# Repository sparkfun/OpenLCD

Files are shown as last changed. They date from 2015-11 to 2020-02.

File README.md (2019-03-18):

OpenLCD 
=========

<table class="table table-hover table-striped table-bordered">
  <tr align="center">
   <td></td>
   <td></td>
   <td></td>
  </tr>
  <tr align="center">
    <td><a href="https://www.sparkfun.com/products/14072">SparkFun 16x2 SerLCD - Black on RGB 3.3V (LCD-14072)</a></td>
    <td><a href="https://www.sparkfun.com/products/14073">SparkFun 16x2 SerLCD - RGB on Black 3.3V (LCD-14073)</a></td>
    <td><a href="https://www.sparkfun.com/products/14074">SparkFun 20x4 SerLCD - Black on RGB 3.3V (LCD-14074)</a></td>
  </tr>
</table>

These AVR-based Serial Enabled LCDs are based on the HD44780 controller, and include an AVR ATmega328P with an Arduino compatible bootloader. They accept control commands via Serial, I2C and SPI. 

This repo contains the firmware that runs on the SerLCD hardware. If you are looking for the Arduino Library to talk to these devices please go [here](https://github.com/sparkfun/SparkFun_SerLCD_Arduino_Library).

And thank you to all those that helped make OpenLCD better:

* **fourstix** - [Creating](https://github.com/sparkfun/OpenLCD/pull/13) an Arduino library to drive OpenLCD directly, added pipe character escaping
* **makinako** - [Changing](https://github.com/sparkfun/OpenLCD/pull/18) EEPROM writes to updates to reduce NVM wear and tear
* **ALittleSlow** - [Fixed](https://github.com/sparkfun/OpenLCD/pull/21) logic bug on ignoreRX

Repository Contents
-------------------
* **/Firmware**
  * **/Examples**
  * **/OpenLCD**

Documentation
--------------
* **[SparkFun SerLCD Arduino Library](https://github.com/sparkfun/SparkFun_SerLCD_Arduino_Library)** - Makes printing to and controlling the SerLCD a snap!
* **[Hookup Guide](https://learn.sparkfun.com/tutorials/avr-based-serial-enabled-lcds-hookup-guide)** - Basic hookup guide for the SparkFun Open LCD Products.
* **[SparkFun Fritzing repo](https://github.com/sparkfun/Fritzing_Parts)** - Fritzing diagrams for SparkFun products.
* **[SparkFun 3D Model repo](https://github.com/sparkfun/3D_Models)** - 3D models of SparkFun products. 
* **[SparkFun Graphical Datasheets](https://github.com/sparkfun/Graphical_Datasheets)** -Graphical Datasheets for various SparkFun products.

Product Versions
----------------
* OpenLCD
  * [LCD-14072](https://www.sparkfun.com/products/14072) - SparkFun 16x2 SerLCD - Black on RGB 3.3V
  * [LCD-14073](https://www.sparkfun.com/products/14073) - SparkFun 16x2 SerLCD - RGB on Black 3.3V
  * [LCD-14074](https://www.sparkfun.com/products/14074) - SparkFun 20x4 SerLCD - Black on RGB 3.3V

License Information
-------------------
The code is beerware; if you see me (or any other SparkFun employee) at the local, and you've found our code helpful, please buy us a round!

Distributed as-is; no warranty is given.

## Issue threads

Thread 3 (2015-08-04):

Libraries for Reuploading the Default Firmware

bboyho, 2015-08-04:
It would be nice to include the additional libraries used for the default firmware in the repository. =) If not, it would be nice to include a link them somehow. I bricked the OpenLCD when trying to upload code to another Arduino. The pins were on the same hardware UART line. Doing a search online, I found the libraries:

SoftPWM library => https://code.google.com/p/rogue-code/wiki/SoftPWMLibraryDocumentation#Download

LiquidCrystalFast library from PJRC => https://www.pjrc.com/teensy/td_libs_LiquidCrystal.html

fourstix, 2018-08-24:
The link for the SoftPWM library in @bboyho 's comment now gives a 404 error.  It looks like the latest version of SoftPWM is now here on github https://github.com/bhagman/SoftPWM , also one can install SoftPWM through the
FWIW,  I second the suggestion to put links in the tutorial.  Also it may be possible to install these Libraries through the Arduino Library manager.  That might be the easiest thing to do.

fourstix, 2018-08-24:
(I don't know why github word-wrapped my comment like that. It should say:)
The link for the SoftPWM library in @bboyho 's comment now gives a 404 error.
It looks like the latest version of SoftPWM is now here on github https://github.com/bhagman/SoftPWM , also it may be possible to install these Libraries through the Arduino Library manager.
FWIW, I second the suggestion to put links in the tutorial.

bboyho, 2018-09-27:
If anyone needs to reupload OpenLCD's default firmware, the zipped libraries have been linked in the [Troubleshooting section](https://learn.sparkfun.com/tutorials/avr-based-serial-enabled-lcds-hookup-guide/troubleshooting) of the tutorial. I followed the "**Add .ZIP Library...**" route since the _Liquid Crystal Fast Library_ does not appear to be in GitHub or included in the Arduino IDE's Library Manager.

Closed 2018-09-27.

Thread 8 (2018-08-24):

Add function for printing the pipe character to the serLCD display

fourstix, 2018-08-24:
Currently pipe | is used as the command setting character, and printing a string with a pipe character may accidentally invoke a display function.  There currently is no way to print a string with a pipe character to the display.

Adding logic to allow pipe to be double escaped || would allow the user to print a pipe symbol as a character in a string without accidentally invoking a display command.

nseidle, 2018-08-25:
Yup! You fixed this in PR #7. Rock on and thanks for the help! Please let me know if you see anything else that needs fixing.

Closed 2018-08-25.

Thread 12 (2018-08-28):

Create library

nseidle, 2018-08-28:
We should really write a library for this device. It would be much easier if a .begin() function took a TwoWire, Serial, or SPI stream and then over-wrote the .print function. We did this on the Qwiic OpenLog product.

fourstix, 2018-08-28:
I already started down that path a bit.  I ported the LiquidCrystal library for Qwiic and the OpenLCD, which could be the I2C /TwoWire part.  It has Print class implemented and all the LiquidCrystal examples ported.  It's publicly available here on github: https://github.com/fourstix/QwiicSerLCD

I thought about expanding it to cover the other communication modes, but I was sure exactly how to best implement the selection of the communication interface type.  Is it best done in the begin() statement or in a constructor?    If there is a Sparkfun preferred way of doing it, I be glad to take a stab at it.  I just need some direction on how Sparkfun would prefer things to be done.

nseidle, 2018-08-28:
Nice!

[This is how](https://www.sparkfun.com/news/2194) we pass in Wire streams to libs so users can use Wire or WireX if they need it. You should be able to overload .being with functions that have TwoWire, SPIClass, and Stream depending on what the user passes in (Wire, SPI, Serial).

nseidle, 2018-08-28:
The [SCD30 library](https://github.com/sparkfun/SparkFun_SCD30_Arduino_Library/blob/master/src/SparkFun_SCD30_Arduino_Library.cpp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) is an ok example of TwoWire class passing.

fourstix, 2018-08-28:
That's Great!  I'll take a look at those examples and run with them.   It looks like I should factor out the initialization of Wire and make that external to the class.

What would like the library class to be called?  SerLiquidCrystal or something else?  Also, any particular example or conventions I should follow?  I can create a repository on Github, and then you could just fork it into Sparkfun once your happy with it.  (I'm a bit new to Git and Github, so please let me know the preferred way to do things.)

fourstix, 2018-08-28:
Hmmm.  LiquidCrystal has a begin function that takes two parameters, col and row, eg. begin(16, 2);  I'm wondering if it would be better to put the stream logic in the form of a constructor, maybe delegating to an init method if needed.  Something like SerLiquidCrystal(TwoWire& wireport).

 SerLiquidCrystal(Wire) lcd;
 lcd.begin(16, 2);

lcd.print("Hello, World!);

nseidle, 2018-08-29:
Library class: OpenLCD? I don't have anything better. Liquid Crystal is pretty well known and I don't want to confuse. Also, SerLCD reads as 'serial' LCD where it looks like you and I are both using Qwiic/I2C.

Sure, in the constructor works. I kind of prefer it in the .begin so that it's clear what options go with what stream. For example (and I haven't thought this through)

    .begin(Wire, 0x35) - where 0x35 is the I2C address of the display.
    .begin(SPI, 1000000) - where 1,000,000 is the SPI freq

.begin(16,2) is not needed as the SerLCD firmware auto-identifies the LCD size (via resistor).

Yep, eventual goal is lcd.print("Hello");

fourstix, 2018-08-29:
Constructor vs begin()
OK, that's a good point. Let's go with overloading begin() instead of overloading constructors.  My main objection was the number of arguments in begin() if one includes the row and column as well as the arguments for the communication type.  Since it's not necessary to specify row and column, it makes sense to put it there.  (If one has more than 5 arguments, other programmers will point and laugh at you.)

Class name
I'll start making the changes in the QwiicLiquidCrystal class, and we can change the name later.

Unfortunately the name OpenLCD is already used for the firmware class name.  It's generally a bad practice to name two classes the same thing, especially when they are somewhat related, but have different functions.

Personally, I like having "LiquidCrystal" in the class name, as this would be an implementation of that class.  I'm leaning toward something like LiquidCrystal_OpenLCD .  As a newbie, that would tell me this is the class to use my OpenLCD display with the LiquidCrystal functions.

fourstix, 2018-08-29:
I should have said I'll make the changes in the QwiicSerLCD repository for now.  We can move them to a new repository with the right class name, later.

fourstix, 2018-08-29:
Come to think of it.  Sparkfun_OpenLCD has a nice ring to it.  That might make a good class name for the Library.

fourstix, 2018-08-29:
I've got the TwoWire and Serial passing done.  Tested I2c via Qwiic and currently testing Serial using Software Serial on an Arduino Pro-Mini 3.3v / 8 MHz.  Working to implement SPI next.

fourstix, 2018-08-30:
@nseidle  I have SPI implemented and have tested Serial and SPI.  It seems to be working.  I2C still works fine as well.  It's available for review at https://github.com/fourstix/QwiicSerLCD

I can re-name it Sparkfun_OpenLCD and create a library directory in OpenLCD and submit a pull request, if you think it's ready.

fourstix, 2018-09-02:
The complete first implementation of the library is ready.  I'll create a pull request.

fourstix, 2018-09-02:
Pull request done.  @nseidle Please let me know what you think.  You're welcome to have @bboyho  or someone from QA review it and (in the words of the Blondie song) Rip 'er to shreds.   I'm always learning and welcome constructive criticism.  Have a great Labor Day!

nseidle, 2018-09-14:
This is really good. I'm going through converting it to fit our lib format. Couple things:

* You shouldn't do a Wire.setClock() before lcd.begin because the .begin() does a Wire.begin which reset the clock back to 100kHz. The fix is to move Wire.setClock after lcd.begin.
* Lots of examples is *really* good. But it's hard to tell where to begin. We put 'ExampleX-' before each example name so it's clear how the examples escalate.
* I changed name to "SerLCD" (dropped Qwiic) since your lib looks to work (nice job!) with SPI. We'll make it work with serial as well. We'll have to tailor a few examples (sub directories) so user knows which examples go with which communication protocol.

nseidle, 2018-09-14:
Another trick:

    #include <SerLCD.h> //Click here to get the library: http://librarymanager/All#SparkFun_SerLCD

fourstix, 2018-09-14:
Great points.  I didn't realize Wire.begin() reset the clock.   There probably are too many examples, since I ported every example from the LiquidCrystal library.  Feel free to omit or add anything you want.

FWIW, I tested the library using SoftwareSerial and it seemed to work, so hopefully I implemented the Serial part correctly.

nseidle, 2018-09-14:
Why is there a delay inside the clear function? This causes your backlight example to run slowly/oddly.

https://github.com/sparkfun/OpenLCD/pull/13/files#diff-7c78931ad272942267b7f87c7b351b24R261

nseidle, 2018-09-14:
Sorry for all the discussion, I'm understanding more of your lib. There is another 50ms delay in the setBacklight function. This is ok, but not ideal. I'm starting to see that the SerLCD firmware (not your lib) is somewhat slow. I think it's related to the amount of time it takes to write to EEPROM the backlight values...but it shouldn't be this slow. I'm still digging. But can you explain why you've got delays in clear() and setBacklight()? My code doesn't work when they're removed... so again I think it's LCD firmware related.

fourstix, 2018-09-14:
Yes, I just added delays empirically to try and reduce flicker or to avoid over-running data sent to the display.  For the backlight changes, it was done to avoid seeing the display messages.  I believe the new set RGB backlight function would avoid them and the delay would probably be unnecessary.  I ran a bunch of tests in a loop, and I think I had the display commands getting missed a few times.  Sometimes the data bytes would appear as a Japanese character rather than be interpreted as a command escape sequence to set the cursor position.  My guess was that I was just sending data too fast, and so I introduced a delay into the code.

fourstix, 2018-09-14:
I should have mentioned I was using the LiquidCrystal HelloWorld sketch to send commands over and over as a test.  It doesn't clear the display, but moves the cursor back to the second line, first column and prints over the previous value.  It prints the same number repeatedly until a second goes by.

 Occasionally, say once every 20 minutes or so, I'd see a glitch, A Japanese character followed by the seconds value sticking out past the normal seconds count.  It seemed to be the worst with SPI, better with SoftwareSerial and best with I2C.  I thought it was random noise from my jumper wires.

nseidle, 2018-09-14:
Excellent. Yep, I agree. There's a

    petSafeDelay(SYSTEM_MESSAGE_DELAY);

inside the changeBLBrightness() function in the OpenLCD firmware that's taking 500ms. That's the delay given me the headache.

There should be a faster way to change the backlight and your changeBacklightRGB() function is perfect. Do you foresee any issues [removing this delay](https://github.com/sparkfun/OpenLCD/blob/master/firmware/OpenLCD/Setting_Control.ino#L160) (and displayFrameBuffer()) from changeBackLightRGB()?

fourstix, 2018-09-14:
No, not at all.  I literally copied them from the previous function (cargo cult programming) thinking that they had to be there for a reason.

nseidle, 2018-09-16:
That is the best use of cargo cult I think I've heard.

Ok, I think I finished re-arranging your library. It's over on [this repo](https://github.com/sparkfun/SparkFun_SerLCD_Arduino_Library). [Request into Arduino](https://github.com/arduino/Arduino/issues/8003) for lib manager inclusion is in the works.

nseidle, 2018-09-16:
I'm going to close these issues out. Let's open new ones on the library repo as necessary.

Closed 2018-09-16.

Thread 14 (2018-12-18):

No Complete command list

justarandomgeek, 2018-12-18:
I can't seem to find a complete command list anywhere - the readme says nothing about commands, and the examples only include the "cheat sheet" list, even the ones that use commands that aren't on it (like custom characters).

lewispg228, 2018-12-18:
Hey @justarandomgeek ,
Sorry we don't currently have a 100% complete command set. Hopefully this [firmware overview](https://learn.sparkfun.com/tutorials/avr-based-serial-enabled-lcds-hookup-guide/firmware-overview) will be useful to you. The table at the top of this hookup guide section contains all of the most useful commands (and includes a few more than the cheat-sheets in the example code).

However, I just noticed that it omits some of the lower decimal values for setting width and line values. These early commands are actually not as useful anymore, because the new LCD screens check a hardware IO pin (pulled HIGH/LOW with hardware) to see what screen it is and sets the width and line values automatically. This is how we maintain the same firmware across all hardware.

Hope this helps!
-Pete

justarandomgeek, 2018-12-18:
It's also still missing all the custom-character commands (the example seems to suggest they ought to start at 0x1B? surely the docs should talk about that...), which indicates to me that it's still incomplete - and really, those are far more interesting than the screen-size ones!

To be clear: I'm wanting to use these screens with my own non-arduino boards, and to do that, I'm gonna have to write my own drivers. To do *that*, I need a complete command list, which I can't seem to find *anywhere*.

lewispg228, 2018-12-18:
Sorry about this. I haven't played around with the [custom char example yet](https://github.com/sparkfun/OpenLCD/blob/master/firmware/Examples/Serial/Example9_Serial_CustomChar/Example9_Serial_CustomChar.ino).  It is one of the more advanced features of these screens, and so we haven't provided as robust documentation for that yet. You are right, it would definitely be nice to get more info about custom char (possibly write up a few more examples) and provide a complete command list.

I will reach out to Nate (who wrote most of this new code for the LCDs). We should be able to pull together a complete command list and have that posted soon.

justarandomgeek, 2018-12-18:
Looking forward to that! Frankly, this is the first time (in 10+ years) that I've bought a SparkFun product and not loved it - and so far I'm *really* disappointed, you guys are slipping. You used to have perfect docs on every product!

nseidle, 2018-12-18:
I've added to the [command table](https://learn.sparkfun.com/tutorials/avr-based-serial-enabled-lcds-hookup-guide/firmware-overview). Should be complete now.

For the pertinent code (and my own notes):

* [Record custom char](https://github.com/sparkfun/OpenLCD/blob/master/firmware/OpenLCD/OpenLCD.ino#L379)
* [Display custom char](https://github.com/sparkfun/OpenLCD/blob/master/firmware/OpenLCD/OpenLCD.ino#L215)
* [Write RGB](https://github.com/sparkfun/OpenLCD/blob/master/firmware/OpenLCD/OpenLCD.ino#L220)
* [Display firmware version](https://github.com/sparkfun/OpenLCD/blob/master/firmware/OpenLCD/OpenLCD.ino#L225)

@justarandomgeek - Have a look and let me know if anything doesn't make sense and I'll add to it.

Closed 2018-12-18.

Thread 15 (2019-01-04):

Three Files with the Extension .ino prevent compile in Windows.

mitag, 2019-01-04:
The firmware consists of several files, three of which have the extension .ino. Yesterday I bought a 20x4 SerLCD and this has the known backlight bug in the firmware. On your side the procedure is described very well, but I could not compile the firmware under Windows 10, because only one file may have the extension .ino. Trying to rename the files to header files caused several problems. So I installed everything under Debian Linux and the three files with the extension .ino don't interfere! I forked the firmware and uploaded the binary file in the fork, because you fixed the bug but didn't upload a binary file. It's not that bad, but just to fix the bug, the steps are too extensive for most users.

[https://www.youtube.com/watch?v=OjE9r5SRFKM](url)

mitag, 2019-01-04:
For now, I've written a small [workeround](https://github.com/mitag/OpenLCD/blob/master/firmware/OpenLCD/README.md) in my fork.

nseidle, 2019-01-04:
Hmm. Weird. It is correct to have multiple INO files in a given directory. It's called tabs; we do it a lot to segment large sketches into various relevant buckets. Arduino opens multiple INOs correctly as shown

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

Sorry for not pushing a hex file. I can get that into the next release.

Thanks for trying to upgrade your 20x4! Let me know if you continue to have issues. I'm going to close this issue because I don't *think* it's an issue. Please correct me if you still have problems.

per1234, 2019-01-06:
The issue turned out to be caused by a bug in arduino-builder, which has already been fixed.

Details: https://github.com/arduino/Arduino/issues/8360#issuecomment-451708341

Closed 2019-01-04.

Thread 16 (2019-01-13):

Reduce the number of EEPROM writes with a 'Save Settings' command or EEPROM.update

makinako, 2019-01-13:
EEPROM.write is used all over the place to save settings on-the-fly (without an explicit 'save settings' command). Since sketches will mostly configure the SerLCD in setup(), this means that every time the sketch starts (at least) it is writing to the EEPROM a number of times for Backlight, Contrast, etc. It also dramatically slows the operation down.

Two solutions:
1. Simply change all calls for EEPROM.write to EEPROM.update, which will check if the value has changed first
2. Remove all the calls to EEPROM.write and have a specific 'Save Settings' command, so that all changes occur only in RAM unless persisted.

Option 2 is the more performant one, but Option 1 is probably preferred because of compatibility.

makinako, 2019-01-25:
Just to put it in context for how I use it, I am connecting to a SerLCD module via UART. At reset, because I can't read what the current settings are I configure the SerLCD module as if it was the first time, which includes contrast, backlight, etc.
On top of this, our device has a sleep mode which turns off the LCD and backlight after a minute of inactivity. The backlight needs to be turned off separately here because the display on/off command doesn't affect it.
Extending this beyond my own application, if someone else allowed these parameters to be adjusted via trimpots or similar, this could result on a rapid succession of EEPROM writes.

The EEPROM.update change would largely get rid of this problem, but another firmware solution at least in my use case would be to read the current settings. I had considered just recording the last settings in my own EEPROM, but we have built 20 of these devices (8-channel audio recorders with LCD UI) and some of them have already had their LCD modules swapped out, which my firmware wouldn't have been aware of.

Hope this clears up the intent at least. There may be a better way to do what I'm doing that I haven't come up with. It's certainly not a high-priority issue but considering it's most likely just a search/replace of EEPROM.write to EEPROM.update it is a fairly easy fix with hopefully some performance implications as well (when updating rapidly). I'd be more than happy to fork/change/test it and submit as a pull request if you were inclined to go down this path!

nseidle, 2019-01-25:
Ah, yes that makes more sense to me now, thanks. Indeed, your update() recommendation is a much better way to go.

I would be thrilled with a PR if you get that far. I plan to spend some time on the firmware early next week so please PR as far as you get and I can pickup where you leave off.

makinako, 2019-01-30:
Changes merged and tested by @nseidle! Closing this baby down.

Closed 2019-01-30.

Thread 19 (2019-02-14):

Turning off system messages

jamesraylittle, 2019-02-14:
I cannot find anywhere in the documentation on how to turn off system messages.
I have also dig through the code a bit and at a glance it does not look like a command of that nature exists.

When using the example code below:

```
  Wire.beginTransmission(LCD_1_ADDR); // transmit to device
  Wire.write('|');
  Wire.write(128);
  Wire.write('|');
  Wire.write(187);
  Wire.write('|');
  Wire.write(188);
  Wire.endTransmission(); //Stop I2C transmission
```

This will then display three separate messages on the LCD.

nseidle, 2019-02-14:
You can turn on/off the splash screen. Are you're asking how to turn off messages like the "Contrast Set" and "New TWI: 0x52" and what not?

jamesraylittle, 2019-02-14:
Correct,

The system messages that happen after updating a value for a setting, such as `Contrast Set...`

nseidle, 2019-02-15:
Should be easy enough to implement. Have you been able to update the firmware on your SerLCD? It will be a while before we get this feature rolled out onto stock units.

nseidle, 2019-02-15:
Lots of changes but [this commit](https://github.com/sparkfun/OpenLCD/commit/2a9d4e230b6623294a690a88542e33e8e07938de) should allow for disable/enable of system messages. If you have the chance, please try it on your hardware.

Attached is HEX file that should be loadable on your display.

[OpenLCD.ino.arduino_standard.zip](https://github.com/sparkfun/OpenLCD/files/2870768/OpenLCD.ino.arduino_standard.zip)

jamesraylittle, 2019-02-15:
I have no tried updating the LCD firmware, but after reading the instructions, it seems easy enough.

I will report back.

jamesraylittle, 2019-02-16:
Are these parameters correct for avrdude?

`avrdude -c avrispmkII -p m328p -P /dev/cu.usbserial-DN02SHFI OpenLCD.ino.arduino_standard.hex`

jamesraylittle, 2019-02-16:
I had a bit of trouble updating the firmware, I had to move over to a windows machine to get the `Fast LCD` library to compile. I wasn't 100% sure on just uploading a the hex file using avrdude, I was getting a lot of timeouts and documentation is lacking in that area.

I looked at the last commit and I noticed this in the file `OpenLCD.ino` starting at line `242`
```
//Enable or disable the displaying of system messages
    else if (incoming == 46) //. character
```

I made the assumption that system messages are left on by default.

Here is my test program:

```

#include <Wire.h>

#define DISPLAY_ADDRESS1 0x72 //This is the default address of the OpenLCD

int _calculateValue(int value, int minValue, int maxValue) {
  return minValue + round( (value / 100.0) * (maxValue - minValue));
}

void setBackground(int red, int green, int blue) {
  /*
  / 128-157 / 0x80-0x9D - Set the primary backlight brightness. 128 = Off, 157 = 100%.
  / 158-187 / 0x9E-0xBB - Set the green backlight brightness. 158 = Off, 187 = 100%.
  / 188-217 / 0xBC-0xD9 - Set the blue backlight brightness. 188 = Off, 217 = 100%.
  */
  int redValue = _calculateValue(red, 128, 157);
  int greenValue = _calculateValue(green, 158, 187);
  int blueValue = _calculateValue(blue, 188, 217);

  Wire.beginTransmission(DISPLAY_ADDRESS1);
  Wire.write('|');
  Wire.write(redValue);
  Wire.write('|');
  Wire.write(greenValue);
  Wire.write('|');
  Wire.write(blueValue);
  Wire.endTransmission();
}

void setup() {
  Wire.begin(); //Join the bus as master

  //By default .begin() will set I2C SCL to Standard Speed mode of 100kHz
  Wire.setClock(400000); //Optional - set I2C SCL to High Speed Mode of 400kHz

  Serial.begin(9600); //Start serial communication at 9600 for debug statements

  //Send the reset command to the display - this forces the cursor to return to the beginning of the display
  Wire.beginTransmission(DISPLAY_ADDRESS1);
  Wire.write('|'); //Put LCD into setting mode
  Wire.write('-'); //Send clear display command
  Wire.write('|'); //setting mode
  Wire.write(46); // disable system messages
  Wire.endTransmission();

  setBackground(0, 0, 0);

  delay(2000);
}

void loop() {
  //red
  setBackground(100, 0, 0);
  delay(10000);

  //green
  setBackground(0, 100, 0);
  delay(10000);

  //blue
  setBackground(100, 0, 0);
  delay(10000);
}
```

I do see a system message that does say `System Messages ON`

Removing the two lines from setup
```
  //Wire.write('|'); //setting mode
  //Wire.write(46); // disable system messages
```

I no longer see the message `System Settings: ON`, but I still see system messages.

nseidle, 2019-02-16:
My bad. I thought the compiler would toggle the bool correctly. It doesn't.

New code pushed. All tested and shiny. Hex is attached (for your convenience). I've also updated the SerLCD library to support the enable/disable commands, added examples as well.

I also added discrete enableSplash() / disableSplash() commands while I was in there.

[OpenLCD.ino.arduino_standard.zip](https://github.com/sparkfun/OpenLCD/files/2872392/OpenLCD.ino.arduino_standard.zip)

Please reopen if you have any other issues.

Closed 2019-02-16.

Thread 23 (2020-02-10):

Persistent faint blue backlight when backlight is set to off (0,0,0) and on initial power on.

rustycoat, 2020-02-10:
Although it is not noticeable in the daytime, there is a constant very faint blue backlight on my unit. This occurs on startup, and also persists even after setting the backlight to 0x00, 0x00, 0x00 with the provided sample code (write: |, -, |, +, 0x00, 0x00, 0x00).

This is over i2c. All other functions seem to perform fine. This has been tested both with direct I2C commands and with the SerLCD library.

fourstix, 2020-02-10:
Hi, I think that's an design artifact from using PWM to control the Blue backlight.  From looking at the source code the blue backlight is controlled by using PWM to dim the output.

If I remember right, PWM is not necessarily an absolutely rock solid line at 100% duty cycle, so I think you are seeing the blue value dimmed to a very small value that is considered zero.

But not actually a perfectly flat zero line, as there are tiny little intervals where the blue light pulses on then off, very briefly, very faintly, that most people wouldn't notice.   But your eyes are sensitive enough to see it to see it as a faint blue glow.  My guess is mine glows just the same as yours, I just don't see it.

I'm not expert and I don't work for Sparkfun. This is just my theory from looking at the code.

Good luck to you.

hbirch, 2020-02-11:
Thanks for the tip -- although I tend to be on the sensitive side when it comes to senses, I do believe it's very easily seen at night. In daytime you can only see it from the side of the LCD. It's about as bright as a dim nightlight or a fading indiglo watch from the 80s.

I would think if they use PWM they would have a conditional for 100% and 0% for true on and off to bypass that needless logic/circuitry in that case. Seems easy enough, though the phrase "the SerLCD v2.5 pulse width modulates the backlight via a 1A BJT transistor" makes me wonder if that transistor is not bypassable. I'm from a software not a hardware background so I am likely misguided on my expectations here as I know what's trivial programmatically may not translate easily onto the circuit board.

That said: a consumer device with the backlight set to "off" should definitely not be illuminating one's bedroom at night. I think the expectation that off is off is fairly reasonable.

If yours can't be seen at night with all the lights off then I'm guessing I may just have a hardware problem where the PWM transistor mentioned above is not manufactured to spec in my individual unit?

nseidle, 2020-02-11:
@hbirch - Thanks for reporting! I agree with fourstix. It's probably a software issue, not hardware. We're looking into it this week.

hbirch, 2020-02-12:
Thanks. Am I right that PR#22 from March 2019 fixes this? It appears to be addressing the same issue.

Unfortunately, this probably means I will need to purchase the FTDI adapter to update firmware...

lewispg228, 2020-02-18:
Hey All,
Thanks for submitting this issue, and thanks to everyone chiming in.

I just verified that pull request #22 does fix this issue. We are currently working on getting this new fimrware (v14) into production. But if you'd like to update your current unit, @rustycoat , then yes, you'll need an FTDI adapter (make sure you use a 3.3V logic level).

We have these in both USB-C connectors:

https://www.sparkfun.com/products/15096

And microB:

https://www.sparkfun.com/products/14050

Thanks again everyone!

Closed 2020-02-18.

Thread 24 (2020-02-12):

Internal i2c pull up on LCD-14074

hbirch, 2020-02-12:
I've run across a reference somewhere that OpenLCD uses a 4.7k internal pull up resistor on SDA/SCL, but that reference was for non-RGB older versions. The hookup diagram on sparkfun makes no mention of any internal pull-up (OR how to disable it).

Does this pull up exist and if so how can it be disabled?

hbirch, 2020-02-12:
Looks like it is labelled on the board. I will note that there is NO documentation whatsoever of this in the hookup guide.

Closed 2020-02-12.

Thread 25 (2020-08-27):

(More a question than bug report)

Just-another-pleb, 2020-08-27:
I don't know an easier way to get in touch with you about this display.
I use Node-Red on a RasPi.

I have a display which I have been told is covered by this bit of software.

Alas I think what you have is for Arduinos / etc, and not for Node-Red.

No problem.

The RasPi and the display are 3.3v, so that is good.
I got it, hooked it up and used someone else's *node* but it would seem I have opened a can of hurt.

I am wanting a node to talk to this display and send it commands like:
backlight (on/off)
cursor (on/off)
blink (on/off)
and x/y positioning for text.
Though if the x/y is missing, it just prints at the next position.

Could you help me?

fourstix, 2020-08-27:
Hi,
I have only played with Node-Red a little bit, but I think what you want to do is to create a custom node for the LCD.   Node-Red has a page how to create custom nodes for a component.  You could use the same commands as in the Arduino based code to control the OpenLCD in your custom node.

There's a guide on creating a new node available here:
https://nodered.org/docs/creating-nodes/

Once you've created the node and tested it.  I believe you can publish it so other Node-Red users can use it.

Good luck,
Gaston

Just-another-pleb, 2020-08-27:
I was kind of hoping that someone else had done that, but their I2C address is 27 but on the RasPi when I scan for it: it shows at address 72.

Thanks.

I think I can *back engineer* it if I look hard and long enough at the Arduino code and the code for the existing node - which has the wrong address.

Thanks though.

I may still need your help.   (If you don't mind)

Just-another-pleb, 2020-08-29:
I am still not really getting any useful/helpful replies from SparkFun on the specs of this.

However, reading what I can find, and what is in this .... system, it should work but isn't.

The display (and AVR) come with this .... _QWIIC_ already loaded.
Looking at that, QWIIC is something to do with the I2C bus.   Great!

We've been over that.   That is how I am connecting it to the RasPi.

But when I start going into that stuff, all the links loop back on themselves.  Which isn't helpful.

In this software I have seen python code to do things.   But is that code run on .....   Where?  On the AVR or the machine connected to the display?

It is confusing to me what is going on.

nseidle, 2020-08-31:
Sorry for the confusion. This repo is the firmware that is loaded onto our displays. It's written in C.

What you are asking for is assistance with the Python code that you will want to run on your RPi. Please see this [repo](https://github.com/sparkfun/Qwiic_SerLCD_Py) and consider posting an issue there.

Just-another-pleb, 2020-08-31:
My problem is that the firmware flashed into the firmware is buggy.

When I change the backlight value a message is printed on the screen informing me of this.

Ok, nice if that would be helpful to me, but it isn't and it causes confusion with the scripts running.

It would be nice if this _feature_ could be disabled.

So what I am (now) looking for is the firmware loaded into the display so I can modify it to not do what it is doing.

Oh, and running the demo scripts that come from Sparkfun on how to use it.
Horrible.

Example 2 and 13.

One of them waits 5 seconds between colour changes.  The other 2 seconds.

Weirdly the one which waits 2 seconds works.  The one which waits 5 seconds the colour names and the colours shown are very much out of sync.

Closed 2020-08-31.

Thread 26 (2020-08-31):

Erroneous messages on display when adjusting back light

Just-another-pleb, 2020-08-31:
After a lot of work, I got the display working.

Attached video explanation:

The display is showing me the time/date/day of week.
And there are a couple of problems visible that the messages are not quite working as they get their positions wrong now and then.
(That's probably an I2C noise issue.  But it is not this problem)

So the display has a _backlight_ of 255,255,255.  Though the colour is not exactly correct as you see it, I think that is more to do with the angle at which is it viewed.   However, the problem will become apparent when you continue watching the video.

I have opened a python (2.x) shell and typed in all but the last command shown here, now.
There is **no** implication that python3.x is supported or there is even a 3.x package available.

`
pi@alarmclock:~/.node-red$ python
Python 2.7.16 (default, Oct 10 2019, 22:02:15)
[GCC 8.3.0] on linux2
Type "help", "copyright", "credits" or "license" for more information.
>>> from __future__ import print_function
>>> import qwiic_serlcd
>>> import time
>>> import sys
>>> myLCD = qwiic_serlcd.QwiicSerlcd()
>>> myLCD.setBacklight(150,0,0)
`

You see the display happily showing the time.

I enter the last line:  `myLCD.setBacklight(150,0,0)` and watch what happens.

The display colour changes.  Not once, not twice but many times.
Simply from me entering the ONE command.

Also see ~~the~~ a colour name top left.
Nothing to do with the colour of the backlight.
Then towards the end you see the screen is covered with numbers.
My suspicion is that is the time being _forced_ all over the place.

So, problems - as I see them:
- There is a `backlight` command.  You enter it with a `r,g,b` parameter and it shows you a whole bunch of back ground colours.
- When the back ground colour is adjusted a random/nominal colour name is printed on the screen.  Top left.
- I have tried the `contrast` command and looking at the screen, I can't see any changes.
It isn't documented how to use other than something like:  _The lower the number, the higher the contrast._
Ok, so if you want a high contrast display, enter `0` - I guess.
It doesn't say if the LOWEST number is `0` or `1`.
And what is the highest number?
(Maybe this is a documentation problem and not for here, but I am quite happy to create a bug report there **IF** I can find the link.)

[LCD.zip](https://github.com/sparkfun/OpenLCD/files/5152699/LCD.zip)

fourstix, 2020-08-31:
>There is no implication that python3.x is supported or there is even a 3.x package available.

There's a Circuit Python library written in Python 3 available for this display. The Arduino examples are available as examples in the Circuit Python library.

 Information and install instructions are available here:  https://github.com/fourstix/Sparkfun_CircuitPython_SerLCD

Just-another-pleb, 2020-08-31:
I am connecting the display - out of the box - to a RasPi.

After messing around and many trips down wasteful links I discovered I had to install SparkFun's qwiic package.

The display then started to work as a display.

It came with a heap of example python files which were nice and did help me get things to where they are/were on the video clip.

But when it comes to adjusting the back light:  all bets are off.

I was _sent here_ because I was showing people how I was talking to the display using `python2.7`.

**you have to use `pythono3.x**

This entire scenario is not nice.
The display is great - in the concept of a display - but when it comes to the firmware showing messages on the screen when I send it a command to adjust the back light is just unbelievable.

And that the colour it says is not exactly related to the colour shown.   That's just not acceptable.

I shall try that new link and see what happens.

Thanks.

Just-another-pleb, 2020-08-31:
I have to say:  At least you **are** helping me.

Sparkfun are **NOT**.

The problem now is that the original lot of stuff I got - for 2.7 - had a lot of example scripts which I could then deconstruct and get the commands to do what I want.

Although there is a *demo script* it assumes all the other boards are there and needs a new kind of MQTT (from what I could read).

Where can I get a list of the commands I can use in Python3.x to talk to the display?

Thanks in advance.

fourstix, 2020-08-31:
I would suggest looking at the python libraries to see how they send commands to the display.

You can take a look inside  the file [sparkfun_serlcd.py](https://github.com/fourstix/Sparkfun_CircuitPython_SerLCD/blob/master/sparkfun_serlcd.py) to see how the CircuitPython library I wrote sends commands to the display.  If you want to see how to send the command's yourself, you will need to go digging.

But the easiest thing to do is to install a library either Sparkfun's Qwiic_Py library or Adafruit's CircuitPython library and then use the library class for the device to handle the commands.   I wrote the CircuitPython library because I wanted to mix and match Sparkfun and Adafruit components in CircuitPython.

Good luck to you!

Just-another-pleb, 2020-08-31:
I have installed the library - or I hope I have.

That is this one - yes?    [https://github.com/fourstix/Sparkfun_CircuitPython_SerLCD](url)

Done, but I am at a loss where the commands are _defined_

Though I am not really able to decode them.   I am able to see it _better_ when they are in code and I can see the structure that way.

What also derails any possibility of me understanding anything is that once I installed the library with the pip3 command, and I `cd` to it and then into the directory for the display - or the one I think is it - there are some files:
`INSTALLER` `LICENSE` `METADATA` `RECORD` and so on.

`INSTALLER` says `pip` and not `pip3`.

All my problems are because I used `pip` to install things and not `pip3`.
To install this I had to use `pip3`.

Why/how is it _LEGAL_ (you tell me a better word) for software which needs to be installed with `pip3` to then use `pip`?

fourstix, 2020-08-31:
Depends on how your Raspbian is set up.  Pip3 is always Python3 but the default Pip can point to either Python 2.7 or 3.

If you click on the link in the highlighted file name in my previous message that will take you directly to the source code file on GitHub and you  can see the actual code there.  Viewing the source file on GitHub is often easier to me, than digging in the directory structure :-)

Just-another-pleb, 2020-09-01:
Yes, I went there.  Thanks.

But I am not able to see the commands as I explained in the other post.

Example scripts are wonderful for me, as I again explained.   I know there is a base line of what the command is and expects.
But reading the source code and trying to extrapolate the command fails for me miserably.

You didn't explain the `INSTALLER` and why it says `pip` and not `pip3`.
I did see the "Depends on how the raspi is set up", but if I am told I need to install it with pip3 because pip installs the wrong version, then the version that is installed also needs to use pip3.

It can't use pip, otherwise when I did the `pip`, I would have installed/got this version, not the older one.

Just-another-pleb, 2020-09-01:
Good news.  Bad news.
Well, honestly that is what it is.

I don't know what/why or anything else.

I did the stuff again (there is a sever feeling of De Ja Vous) but for python3.

All the stuff.....

The node-red flow didn't show anything when run.

Honestly.  I don't know.

The flow is now working.

But the original problem persists:

When I change the background colour, the display shows/scrolls through several colours and there are messages printed on the screen which were not asked for by me.

I'll now go to the newer link and post there.

Just-another-pleb, 2020-09-01:
Oh sorry.   Closed now.

Closed 2020-09-01.

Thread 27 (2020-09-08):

Please add a command to disable serial input

ArizonaClark, 2020-09-08:
I would like to request a new command to ignore serial input (separate from the "ignore-RX on reset"), which would have the controller ignore anything happening on the serial RX line.  (It should be "volatile" in that it goes away whenever the display is reset or power cycled, IMHO.)  To maintain symmetry (always a good idea) there should also be disable commands for SPI and I2C.  (At the risk of pointing out the obvious, if these were "non-volatile" [as is the "ignore-RX on reset"], it would be too easy to "brick" the processor, thus best to make them "volatile".)

For "why", please see this Forum thread: https://forum.sparkfun.com/viewtopic.php?f=63&t=53788

alexandertmills, 2021-11-26:
Any update on this? Fix would be greatly appreciated.

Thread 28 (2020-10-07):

Characters being deleted when changing backlight?

mrmakeit, 2020-10-07:
Getting a weird bug whenever I try to change the backlight over I2C.  Any time I do so, the screen will delete a character, usually the last one from the current message, though repeating the change will delete more and more characters.   Any idea why this is happening?

nseidle, 2020-10-07:
Thanks for reporting. Do you have example code that demonstrates the issue so we can reproduce?

mrmakeit, 2020-10-07:
```
import qwiic_serlcd
lcd = qwiic_serlcd.QwiicSerlcd()
lcd.begin()
lcd.setContrast(5)
lcd.clearScreen()
lcd.print("Hello World")
lcd.setBacklight(0,0,0)
#'d' should now disappear from 'World'
lcd.setBacklight(100,100,255)
#'l' should now disappear from 'World'
```

nseidle, 2020-10-07:
Ah, this repo is the firmware that runs on the LCD. I suspect it's python library related. I've moved your issue to [that repo](https://github.com/sparkfun/Qwiic_SerLCD_Py/issues/4).

mrmakeit, 2020-10-07:
I've had the same issue with an arduino setup as well... Originally thought it was the arduino library, so I tested it with the above python.

nseidle, 2020-10-07:
Ok, feel free to post an example problem sketch on the [Arduino library](https://github.com/sparkfun/SparkFun_SerLCD_Arduino_Library/issues). If we pin it down to firmware on the LCD, then... well, I'll move some issues again :)

Closed 2020-10-07.

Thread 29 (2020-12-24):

Circular Buffer for 2004 not long enough

andrewcharnley, 2020-12-24:
More than 32 characters crashes the display. I've not had a chance to investigate further but it is consistent. This is a problem for those of us doing DMA writes of the entire screen.

nseidle, 2020-12-28:
Sorry, I need to get an issue template on this repo:

What micro or processor are you using to drive the display? What interface (I2C, serial, or SPI)? What driver (our Arduino library, probably your own)?

Code to replicate the issue would be immensely helpful.

Can you be more specific about the crash? Unit freezes until power cycle, unit displays garbage, etc.

I suspect you're hitting the 32 byte I2C buffer limit used in Arduino (the limit is in our peripheral. Not knowing your setup I can only guess that you might as well). Again, without knowing how you're interfacing to the display, I'm really just guessing.

andrewcharnley, 2020-12-28:
Sounds plausable. I2C using a NRF52.

I work around it by DMA'ing a row in 4 goes with a timer and counter. You should be able to easily replicate it, just write/print more than a line (line and a half will do it) and the display will lock up.

nseidle, 2020-12-28:
What is the size of the I2C buffer on nRF52?

I can replicate with an Artemis. Unit stops responding to I2C commands until power cycle.

     lcd.print("1234567890123456789012345678901"); //Good
  //lcd.print("12345678901234567890123456789012"); //Good
  //lcd.print("123456789012345678901234567890123"); //Good
  //lcd.print("1234567890123456789012345678901234"); //Fails

Curiously 33 bytes works. It's not immediately clear to me why the [I2C ISR](https://github.com/sparkfun/OpenLCD/blob/master/firmware/OpenLCD/System_Functions.ino#L49) is going off into never never land but I do believe it's Arduino core / I2C 32 byte buffer related.

Thanks for reporting. We won't be hacking the arduino core to support larger I2C buffers. For now your best solution is to limit your writes to 32 bytes. Let me know if you're using our [Arduino library](https://github.com/sparkfun/SparkFun_SerLCD_Arduino_Library). If you are, we can modify the [write function](https://github.com/sparkfun/SparkFun_SerLCD_Arduino_Library/blob/master/src/SerLCD.cpp#L403) to break large transfers into I2C buffer sized chunks.

andrewcharnley, 2020-12-28:
I generally use Arduino as a last resort, but since the firmware is embedded I don't see why you can't implement and include a patch file (in the rare case someone really wants to apply it manually). Personally I just want it working out the box, which I guess is the same for most people. Is the 32 byte referring to the circular buffer? I believe the Arduino is servicing the I2C buffer by interrupt but my experience with the HD controller used in the display is it uses a 50us delay between characters, so it's probably a race between completing those and the buffer filling up at 100kbs.

The I2C buffer on the NRF52 is limited only by RAM as it's DMA based. I wired up a timer to write chucks of 20 bytes one after the other with a little delay to allow the display/arduino code to recover. It works well enough.

fourstix, 2020-12-29:
I believe the 32 byte limitation is a limitation of the Wire library.

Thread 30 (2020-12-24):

Map special characters to unused ascii characters

andrewcharnley, 2020-12-24:
Please use the logic of the original HD chip! Those of us doing DMA writes of the whole screen can not use adhoc commands to change characters.

nseidle, 2020-12-28:
What micro or processor are you using to drive the display? What interface (I2C, serial, or SPI)? What driver (our Arduino library, probably your own)?

Your issue title is related to special characters but you're reporting issues with pass through low level HD44780 commands? Your issue is unfortunately too sparse for us to be of any help.

andrewcharnley, 2020-12-28:
I2C, NRF52.

I currently implement a screen buffer of 4x20 bytes which I write to and push out to the display. Apart from the other issue that I mentioned in the other thread, when special characters are used the command character must be used which prevents use of a screen buffer (because it's two bytes).

The simple solution is not to reinvent the wheel - use the non-print characters as spaceholders (0x0 to 0x20 or 0x7F) to a) invoke command options and b) to write special characters.

nseidle, 2020-12-28:
I welcome a PR. There's over 15 years of history to this product so you may be battling reverse compatibility of prior models.

andrewcharnley, 2020-12-28:
Time for a version 2.0 then. Solve all these problems and you have a one stop product for more professional use cases (DMA). ;)

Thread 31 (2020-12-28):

Use a separate command for writing flash

andrewcharnley, 2020-12-28:
Having a multi coloured display is a real bonus, I can use it to indicate errors and the like.

But if I flash/change colours a few times that's a couple writes to EPROM, and the 100,000 count will eventually be used up. It also slows the whole system down by locking the CPU while it writes.

Solution is to remove the auto-save and map it to a character in the 0x0 to 0x20 region.

nseidle, 2020-12-29:
I'm hesitant to implement mapping directly to the 0x0-0x19 non-visible region. Many users attach SerLCD to a serial stream that may include all sorts of garbage characters. They could quickly bork their display is the system settings are mapped to non-vis characters.

FWIW, flash is a lot more resilient than quoted. Checkout [Flash Thrasher](https://github.com/nseidle/Flash_Thrasher).

We could add an option to disable auto-saving of screen color to flash but disabling the current auto-record structure would break a lot of existing user code.

We could map a variety of commands to the 0x0 to 0x19 region. 0x20 is space char. We'd need to have a special system command to enable these 'direct' commands so they aren't enabled by default (to avoid the garbage serial stream issue mentioned above). Do you have a proposed command map? Here's my [first take](https://docs.google.com/spreadsheets/d/1ef0zw44_iirxl6l-Avq46-_pAdA3nhGVm6_5g_Z6xIU/edit?usp=sharing). We'll have to create a setting in the library to enable writing of direct commands (off by default) so users who have <v2.0 LCD firmware still have a functioning library.

This is quickly growing in complexity for little added value.

fourstix, 2020-12-29:
Ugh. Personally, I hate adding all these unusual command codes one can accidentally trip over.  The ASCII control characters have well-defined meanings, and do often appear in text streams.

I'd recommend a two character sequence, using Escape (0x1B) or one of the Device Control 1-4 (0x11 to 0x14) characters followed by a command character for a particular command.  That's less error-prone and fits into the ASCII model better than redefining several control codes to mean something other than their conventional descriptions.

From the spreadsheet, it looks like you are defining TAB (0x09) to be a command character.  That would be bad.

andrewcharnley, 2020-12-29:
Fourstix -> It's not bad if the HD controller doesn't support it, which it doesn't. If you're expecting to not read the documentation and send the display crap that's your problem, it absolutely should not mean sacrificing performance for the wider audience.

If they are sending garbage over serial there is the same chance that they send say 0x03 or the '|' command character, so I don't see the difference. '|' is a printable character so it shouldn't be used for the command. Make the whole thing a none critical issue by only writing to flash with a particular sequence , i.e four specific bytes.  Another reason for not writing the flash every time is interrupt servicing is turned off and because the simple Atmega only has a single buffer it may not be quick enough to catch the next incoming byte (I2C etc).

If compatibility is important may I suggest a command which switches it into v2 mode, then duplicate everything (assuming there is the memory).

Little added value -> well there's currently not a single character based LED that can handle DMA transactions with the nice features which this display has (specifically the background colours). It will be the go to model for more advanced users.

Only the 8 special characters need mapping into the 0x0 to 0x19 region, plus the command character. I'd then extend my framebuffer by 20 bytes and it would be enough to handle commands for changing colour and the like.

andrewcharnley, 2020-12-29:
Also to put it into context why DMA is important, on the AtMega2560 arduino with the same display + i2c backpack the delays inherent to the HD controller meant the ADC would read at 100Hz. Using the NRF52 with DMA to the Sparkfun screen I'm able to hit 50KHz.

fourstix, 2020-12-29:
I would be the first to agree that the Pipe (|) character was an unfortunate choice as the command escape character. (Personally, I would chose ESC 0x1B that is what the ASCII spec specifies. But Pipe has a rather dubious history as an escape character in old data streams, and that's probably why it was used.)

But re-defining more ASCII control codes would just make a bad situation worse.  After all, it is reasonable to expect a serial device to respond to an ASCII text stream according to spec.  And the ASCII characters 0x00 to 0x7F have all had well defined meanings since 1967.  (One might use a character above 0x7F in the "Extended Ascii" range as a control character, without causing many problems, but then someone in Europe or Japan will stumble on it.)

Maybe what we really need as a feature is the ability to switch the display to use another character as the command control character.   Then you could chose your character and and I could have mine.   Also this would be backwards compatible with the previous versions.

PS. The buffer in Wire is just a 32 char array.  You are giving way to much credit by thinking they use a circular buffer. ;-)

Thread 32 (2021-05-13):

Checksums or similar for critical commands

JamesB7, 2021-05-13:
Hello,
Would you please consider requiring a checksum, or at least a duplicate byte, for critical commands?
For example, if a bit flip causes the 'change I2C address' command to be called, the hardware that uses the device is no longer usable. End users can't be expected to fix such a problem, either. The commands, as they stand now, have this introduced source of unreliability.
Thanks!
James

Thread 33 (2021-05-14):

'Ignore RX' needs to set true or false...

JamesB7, 2021-05-14:
Right now, it toggles.
Toggling is completely useless and wrong.
This means it cannot be sent as part of a SPI or I2C startup. If the host board restarts for whatever reason, while keeping the device powered (this will certainly happen), the host board will turn OFF 'Ignore RX'.

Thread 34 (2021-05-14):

Please reset mode between I2C transactions

JamesB7, 2021-05-14:
The start of an I2C transaction needs to be in a defined mode. That or there needs to be a sequence of bytes that, in *all modes*, resets the state.
If it's not (and as it stands, from what I can see), it is completely impossible to make a reliable driver for this product. Yes, it may work 99% of the time, but it cannot be made reliable.
Right now, there is no 'correct'.

JamesB7, 2021-05-14:
If this is hard to implement generally, at the very least have it please have it reset back to MODE_NORMAL if the buffer is empty.
This is likely to often be the case, and so a proper I2C driver could get the OpenLCD back into a known state just by delaying.

As it stands right now, if I (for example) send the setting command '|' and the transaction ends (due to a bit flip, for example), if I send text data in the next transaction I'm in real trouble, especially given the many EEPROM-modifying commands.

This is really very important.

Thank you.

James

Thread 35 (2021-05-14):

Ability to set 'ignore RX', set contrast, set RGB without writing EEPROM

JamesB7, 2021-05-14:
In my application, I do not need the device to write to EEPROM -- really, for anything. I expect to be streaming 'set RGB' quickly to do fades between colors (for example, fade white to red when an error occurs, fade back afterward), and this will certainly wear the EEPROM out if it writes it.

It would be very helpful to have a pair of commands to disable/re-enable EEPROM writes when changing settings. (These would be sent during initialization and so should not themselves be saved.)

Thank you!

James

JamesB7, 2021-05-14:
Would you accept a patch for this if I were to write one?
I'd do it by adding commands to the pipe command set -- there's plenty of room there, and I can do this simply.
(A command of this sort would also protect the device against bricking. If bits flip, and it writes a new I2C address to EEPROM, for example, no more screen. If I put the device in a 'EEPROM write disable' state *most* of the time, odds are, end users will not run into a problem.)

nseidle, 2021-05-14:
Yes please, PRs are welcome. Our greatest priority is to maintain reverse compatibility so as long as it's new commands, we should be fine.

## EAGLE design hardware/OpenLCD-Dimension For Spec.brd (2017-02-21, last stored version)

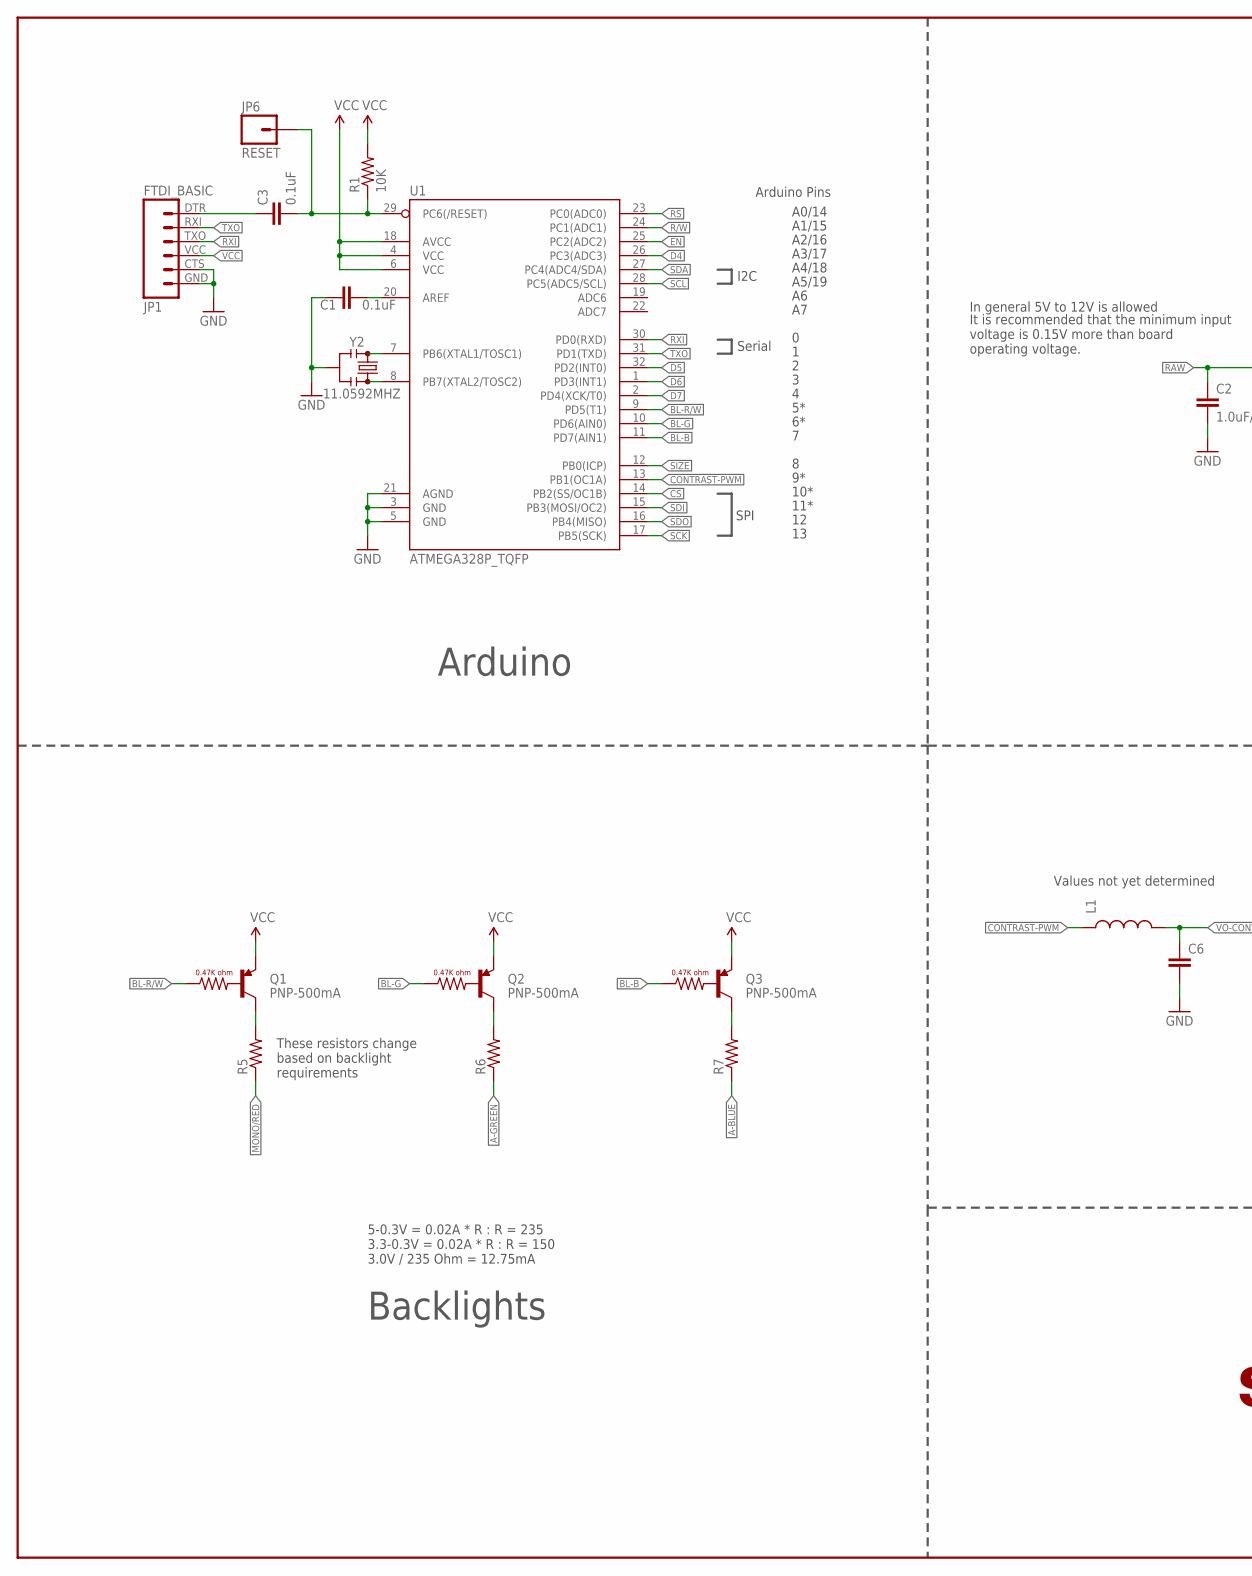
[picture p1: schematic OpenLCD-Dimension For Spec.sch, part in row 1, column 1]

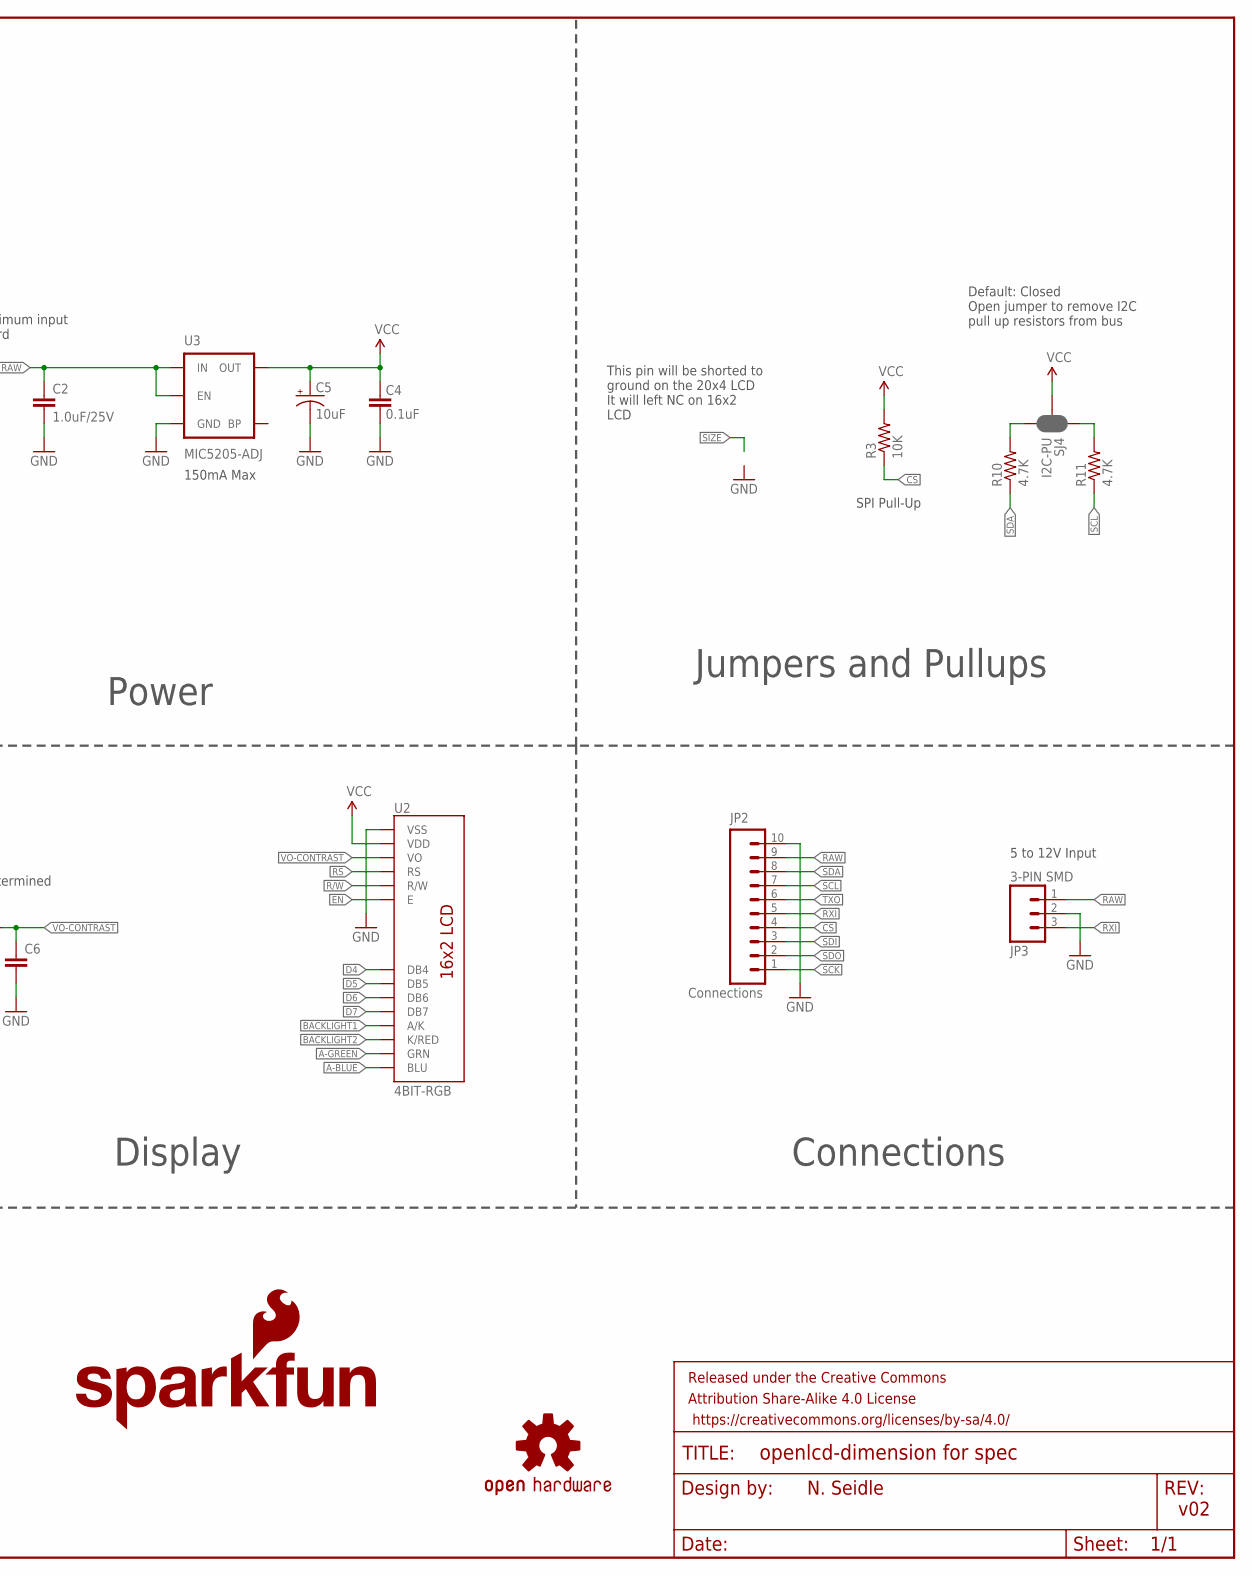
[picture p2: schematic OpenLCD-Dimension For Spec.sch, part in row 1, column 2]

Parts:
C1, C3, C4: 0.1uF; 0603-CAP
C2: 1.0uF/25V; 0805-CAP
C5: 10uF; EIA3216
C6: CAP0603-CAP; 0603-CAP
FRAME1: FRAME-LEDGER; CREATIVE_COMMONS
JP1: FTDI_BASIC
JP2: Connections; 1X10
JP3: 3-PIN SMD; JST-3-PTH-VERT
JP6: RESET; 1X01
L1: INDUCTOR0603; 0603
LOGO1: SFE_LOGO_NAME_FLAME.1_INCH; SFE_LOGO_NAME_FLAME_.1
Q1, Q2, Q3: PNP-500mA; SOT23-3
R1, R3: 10K; 0603-RES
R5, R6, R7: 240; 0603-RES
R10, R11: 4.7K; 0603-RES
SJ4: I2C-PU; PAD-JUMPER-3-NC_BY_PASTE_YES_SILK_FULL_BOX
U1: ATMEGA328P_TQFP; TQFP32-08
U2: 4BIT-RGB; LCD-16X2_NOSILK-KIT-4BIT
U3: MIC5205-ADJ; SOT23-5
U$4: OSHW-LOGOS; OSHW-LOGO-S
Y2: 11.0592MHZ; RESONATOR-SMD

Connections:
!CS: JP2.4, R3.1, U1.14 (PB2(SS/OC1B))
A-BLUE: R7.1, U2.18 (BLU)
A-GREEN: R6.1, U2.17 (GRN)
AREF: C1.2, U1.20 (AREF)
BACKLIGHT1: U2.15 (A/K)
BACKLIGHT2: U2.16 (K/RED)
BL-B: Q3.1 (B), U1.11 (PD7(AIN1))
BL-G: Q2.1 (B), U1.10 (PD6(AIN0))
BL-R/W: Q1.1 (B), U1.9 (PD5(T1))
CONTRAST-PWM: L1.1, U1.13 (PB1(OC1A))
D4: U1.26 (PC3(ADC3)), U2.11 (DB4)
D5: U1.32 (PD2(INT0)), U2.12 (DB5)
D6: U1.1 (PD3(INT1)), U2.13 (DB6)
D7: U1.2 (PD4(XCK/T0)), U2.14 (DB7)
DTR: C3.1, JP1.DTR (1)
EN: U1.25 (PC2(ADC2)), U2.6 (E)
GND: C1.1, C2.2, C4.1, C5.C (-), C6.2, JP1.CTS (5), JP1.GND (6), JP2.10, JP3.2, U1.3 (GND), U1.5 (GND), U1.21 (AGND), U2.1 (VSS), U3.2 (GND), Y2.2
MONO/RED: R5.1
unnamed: Q1.3 (C), R5.2
unnamed: U1.8 (PB7(XTAL2/TOSC2)), Y2.3
unnamed: U1.7 (PB6(XTAL1/TOSC1)), Y2.1
unnamed: Q2.3 (C), R6.2
unnamed: Q3.3 (C), R7.2
unnamed: R11.2, SJ4.1
unnamed: R10.2, SJ4.3
R/W: U1.24 (PC1(ADC1)), U2.5 (R/W)
RAW: C2.1, JP2.9, JP3.1, U3.1 (IN), U3.3 (EN)
RS: U1.23 (PC0(ADC0)), U2.4 (RS)
RST: C3.2, JP6.1, R1.1, U1.29 (PC6(/RESET))
RXI: JP1.TXO (3), JP2.5, JP3.3, U1.30 (PD0(RXD))
SCK: JP2.1, U1.17 (PB5(SCK))
SCL: JP2.7, R11.1, U1.28 (PC5(ADC5/SCL))
SDA: JP2.8, R10.1, U1.27 (PC4(ADC4/SDA))
SDI: JP2.3, U1.15 (PB3(MOSI/OC2))
SDO: JP2.2, U1.16 (PB4(MISO))
SIZE: U1.12 (PB0(ICP))
TXO: JP1.RXI (2), JP2.6, U1.31 (PD1(TXD))
VCC: C4.2, C5.A (+), JP1.VCC (4), Q1.2 (E), Q2.2 (E), Q3.2 (E), R1.2, R3.2, SJ4.2, U1.4 (VCC), U1.6 (VCC), U1.18 (AVCC), U2.2 (VDD), U3.5 (OUT)
VO-CONTRAST: C6.1, L1.2, U2.3 (VO)

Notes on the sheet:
10*
11*
A0/14
A1/15
A2/16
A3/17
A4/18
A5/19
Arduino Pins
SPI
Serial
I2C
Arduino
Display
Backlights
Connections
Power
5 to 12V Input
5-0.3V = 0.02A * R : R = 235 3.3-0.3V = 0.02A * R : R = 150 3.0V / 235 Ohm = 12.75mA
SPI Pull-Up
N. Seidle
v02
Jumpers and Pullups
Default: Closed Open jumper to remove I2C pull up resistors from bus
It is recommended that the minimum input voltage is 0.15V more than board operating voltage.
In general 5V to 12V is allowed
150mA Max
Values not yet determined
These resistors change based on backlight requirements
This pin will be shorted to ground on the 20x4 LCD It will left NC on 16x2 LCD

Board: 2 copper layers, 30 parts (3 on the bottom side), 35 nets, no tracks yet.

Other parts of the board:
U$1: LOGO-SFESK; SFE-LOGO-FLAME

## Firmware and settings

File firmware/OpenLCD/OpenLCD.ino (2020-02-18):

/*
  OpenLCD is an LCD with serial/i2c/spi interfaces.
  By: Nathan Seidle
  SparkFun Electronics
  Date: February 13th, 2015
  License: This code is public domain but you buy me a beer if you use this and we 
  meet someday (Beerware license).

  OpenLCD gives the user multiple interfaces (serial, I2C, and SPI) to control an LCD. SerLCD 
  was the original serial LCD from SparkFun that ran on the PIC 16F88 with only a serial interface 
  and limited feature set. This is an updated serial LCD.

  Select 'SparkFun SerLCD' as the board. We use an ATmega328P running at 11.0592MHz in 
  order to have error free serial comm.

  v11: 
    Add faster backlight command
    Change EEPROM write() to update()  

  v12:
    Add command to disable system messages displayed when settings change (contrast, UART, etc).
    Add discrete commands to enableSplash and disableSplash. Better for embedded systems if it needs to disable splash.

  v13:
    emergency reset bug fixed - https://github.com/sparkfun/OpenLCD/pull/21
    
  v14:
    enable true off for blue LED - https://github.com/sparkfun/OpenLCD/pull/22
*/

//Firmware version. This is sent when requested. Helpful for tech support.
const byte firmwareVersionMajor = 1;
const byte firmwareVersionMinor = 4;

#include <Wire.h> //For I2C functions
#include <SPI.h> //For SPI functions
#include <LiquidCrystalFast.h> //Faster LCD commands. From PJRC https://www.pjrc.com/teensy/td_libs_LiquidCrystal.html
#include <EEPROM.h>  //Brightness, Baud rate, and I2C address are stored in EEPROM
#include "settings.h" //Defines EEPROM locations for user settings
#include <avr/wdt.h> //Watchdog to prevent system freeze
#include <avr/sleep.h> //Needed for sleep_mode
#include <avr/power.h> //Needed for powering down perihperals such as the ADC/TWI and Timers

#include <SoftPWM.h> //Software PWM for Blue backlight: From https://github.com/bhagman/SoftPWM
//SoftPWM uses Timer 2

LiquidCrystalFast SerLCD(LCD_RS, LCD_RW, LCD_EN, LCD_D4, LCD_D5, LCD_D6, LCD_D7);

byte characterCount = 0;
char currentFrame[DISPLAY_BUFFER_SIZE]; //Max of 4 x 20 LCD

byte customCharData[8]; //Records incoming custom character data
byte customCharSpot = 0 ; //Keeps track of where we are in custCharData array
byte customCharNumber = 0; //LCDs can store 8 custom chars, this keeps track

//New variables for Set RGB command
byte rgbData[3]; //Records incoming backlight rgb triplet
byte rgbSpot = 0 ; //Keeps track of where we are in rgbData array

enum displayMode
{
  MODE_NORMAL, //No mode, just print
  MODE_COMMAND, //Used to indicate if a command byte has been received
  MODE_SETTING, //Used to indicate if a setting byte has been received
  MODE_CONTRAST, //First setting mode, then contrast change mode, then the value to change to
  MODE_TWI, //First setting mode, then I2C mode, then change I2C address
  MODE_RECORD_CUSTOM_CHAR, //First setting mode, then custom char mode, then record 8 bytes
  MODE_SET_RGB //First setting mode, then RGB mode, then get 3 bytes
} currentMode = MODE_NORMAL;

// Struct for circular data buffer
// Data received over UART, SPI and I2C are all sent into a single buffer
struct dataBuffer
{
  byte data[BUFFER_SIZE];  // THE data buffer
  volatile byte head;  // store new data at this index
  volatile byte tail;  // read oldest data from this index
} buffer;  // our data buffer is creatively named - buffer

void setup()
{
  wdt_reset(); //Pet the dog
  wdt_disable(); //We don't want the watchdog during init

  //During testing reset everything
  //for(int x = 0 ; x < 200 ; x++)
  //  EEPROM.write(x, 0xFF);

  setupSystemMessages(); //Load settings, such as displaySystemMessages
  
  setupLCD(); //Initialize the LCD

  setupContrast(); //Set contrast

  setupBacklight(); //Turn on any backlights

  setupSplash(); //Read and display the user's splash screen

  setupCustomChars(); //Pre-load user's custom chars from EEPROM

  setupUART(); //Setup serial, check for emergency reset after the splash is done

  setupSPI(); //Initialize SPI stuff (enable, mode, interrupts)

  setupTWI(); //Initialize I2C stuff (address, interrupt, enable)

  setupPower(); //Power down peripherals that we won't be using

  interrupts();  // Turn interrupts on, and let's go
  wdt_enable(WDTO_250MS); //Unleash the beast
}

void loop()
{
  wdt_reset(); //Pet the dog

  //The TWI interrupt will fire whenever it fires and adds incoming I2C characters to the buffer
  //As does the SPI interrupt
  //Serial is the only one that needs special attention
  serialEvent(); //Check the serial buffer for new data

  while (buffer.tail != buffer.head) updateDisplay(); //If there is new data in the buffer, display it!

  //Once we've cleared the buffer, go to sleep
  sleep_mode(); //Stop everything and go to sleep. Wake up if serial character received
}

// updateDisplay(): This beast of a function is called by the main loop
// If the data relates to a commandMode or settingMode will be set accordingly or a command/setting
// will be executed from this function.
// If the incoming data is just a character it will be displayed
void updateDisplay()
{
  wdt_reset(); //Pet the dog

  // First we read from the oldest data in the buffer
  byte incoming = buffer.data[buffer.tail];
  buffer.tail = (buffer.tail + 1) % BUFFER_SIZE;  // and update the tail to the next oldest

  //If the last byte received wasn't special
  if (currentMode == MODE_NORMAL)
  {
    //Check to see if the incoming byte is special
    if (incoming == SPECIAL_SETTING) //SPECIAL_SETTING is 127
    {
      currentMode = MODE_SETTING;
    }
    else if (incoming == SPECIAL_COMMAND) //SPECIAL_COMMAND is 254
    {
      currentMode = MODE_COMMAND;
    }
    else if (incoming == 8) //Backspace
    {
      if (characterCount == 0) characterCount = settingLCDwidth * settingLCDlines; //Special edge case

      characterCount--; //Back up

      currentFrame[characterCount] = ' '; //Erase this spot from the buffer
      displayFrameBuffer(); //Display what we've got
    }
    else //Simply display this character to the screen
    {
      SerLCD.write(incoming);

      currentFrame[characterCount++] = incoming; //Record this character to the display buffer
      if (characterCount == settingLCDwidth * settingLCDlines) characterCount = 0; //Wrap condition
    }
  }
  else if (currentMode == MODE_SETTING)
  {
    currentMode = MODE_NORMAL; //We assume we will be returning to normal

    //LCD width and line settings
    if (incoming >= 3 && incoming <= 7) //Ctrl+c to Ctrl+g
    {
      //Convert incoming value down to 0 to 4
      changeLinesWidths(incoming - 3);
    }
    //Software reset
    else if (incoming == 8) //Ctrl+h
    {
      while (1); //Hang out and let the watchdog punish us
    }
    //Enable / disable splash setting
    else if (incoming == 9) //Ctrl+i
    {
      changeSplashEnable();
    }
    //Save current buffer as splash
    else if (incoming == 10) //Ctrl+j
    {
      changeSplashContent();
    }
    //Set baud rate
    else if (incoming >= 11 && incoming <= 23) //Ctrl+k to ctrl+w
    {
      //Convert incoming value down to 0
      changeUARTSpeed(incoming - 11);
    }
    //Set contrast
    else if (incoming == 24) //Ctrl+x
    {
      currentMode = MODE_CONTRAST; //Go to new mode
      //We now grab the next character on the next loop and use it to change the contrast
    }
    //Set TWI address
    else if (incoming == 25) //Ctrl+y
    {
      currentMode = MODE_TWI; //Go to new mode
      //We now grab the next character on the next loop and use it to change the TWI address
    }
    //Control ignore RX on boot
    else if (incoming == 26) //Ctrl+z
    {
      changeIgnore();
    }
    //Record custom characters
    else if (incoming >= 27 && incoming <= 34)
    {
      //User can record up to 8 custom chars
      customCharNumber = incoming - 27; //Get the custom char spot to record to

      currentMode = MODE_RECORD_CUSTOM_CHAR; //Change to this special mode
    }

    //Display custom characters, 8 characters allowed, 35 to 42 inclusive
    else if (incoming >= 35 && incoming <= 42)
    {
      SerLCD.write(byte(incoming - 35)); //You write location zero to display customer char 0
    }
    //Set Backlight RGB in one command to eliminate flicker
    else if (incoming == 43) //+ character
    {
      currentMode = MODE_SET_RGB; //Go to new mode
    }
    //Display current firmware version
    else if (incoming == 44) //, character
    {
      displayFirmwareVersion();
    }
    //Clear screen and buffer
    else if (incoming == 45) //- character
    {
      SerLCD.clear();
      SerLCD.setCursor(0, 0);

      clearFrameBuffer(); //Get rid of all characters in our buffer
    }
    //Enable the displaying of system messages
    else if (incoming == 46) //. character
    {
      enableDisplaySystemMessages();
    }
    //Disable the displaying of system messages
    else if (incoming == 47) // / character
    {
      disableDisplaySystemMessages();
    }
    //Enable the splash screen at power on
    else if (incoming == 48) //0 character
    {
      enableSplash();
    }
    //Disable the splash screen at power on
    else if (incoming == 49) //1 character
    {
      disableSplash();
    }

    //If we get a second special setting character, then write it to the display
    //This allows us to print a pipe by escaping it as a double
    else if (incoming == 124) //| character
    {
      SerLCD.write(incoming);

      currentFrame[characterCount++] = incoming; //Record this character to the display buffer
      if (characterCount == settingLCDwidth * settingLCDlines) characterCount = 0; //Wrap condition
    }

    //The following commands start at integer value 128
    
    //Backlight Red or standard white
    else if (incoming >= SPECIAL_RED_MIN && incoming <= (SPECIAL_RED_MIN + 29))
    {
      byte brightness = map(incoming, SPECIAL_RED_MIN, SPECIAL_RED_MIN + 29, 0, 255); //Covert 30 digit value to 255 digits
      changeBLBrightness(RED, brightness);
    }
    //Backlight Green
    else if (incoming >= SPECIAL_GREEN_MIN && incoming <= (SPECIAL_GREEN_MIN + 29))
    {
      byte brightness = map(incoming, SPECIAL_GREEN_MIN, SPECIAL_GREEN_MIN + 29, 0, 255); //Covert 30 digit value to 255 digits
      changeBLBrightness(GREEN, brightness);
    }
    //Backlight Blue
    else if (incoming >= SPECIAL_BLUE_MIN && incoming <= (SPECIAL_BLUE_MIN + 29))
    {
      byte brightness = map(incoming, SPECIAL_BLUE_MIN, SPECIAL_BLUE_MIN + 29, 0, 255); //Covert 30 digit value to 255 digits
      changeBLBrightness(BLUE, brightness);
    }
  }
  else if (currentMode == MODE_TWI)
  {
    //Custom TWI address
    changeTWIAddress(incoming);

    currentMode = MODE_NORMAL; //Return to normal operation
  }
  else if (currentMode == MODE_COMMAND) //Deal with lower level commands
  {
    currentMode = MODE_NORMAL; //In general, return to normal mode

    if (incoming >> 7 == 1) //This is a cursor position command
    {
      incoming &= 0x7F; //Get rid of the leading 1

      byte line = 0;
      byte spot = 0;
      if (incoming >= 0 && incoming <= 19)
      {
        spot = incoming;
        line = 0;
      }
      else if (incoming >= 64 && incoming <= 83)
      {
        spot = incoming - 64;
        line = 1;
      }
      else if (incoming >= 20 && incoming <= 39)
      {
        spot = incoming - 20;
        line = 2;
      }
      else if (incoming >= 84 && incoming <= 103)
      {
        spot = incoming - 84;
        line = 3;
      }

      SerLCD.setCursor(spot, line); //(x, y) - Set to X spot on the given line
    }
    else if (incoming >> 6 == 1) //This is Set CGRAM address command
    {
      //User is trying to create custom character

      incoming &= 0b10111111; //Clear the ACG bit

      //User can record up to 8 custom chars
      customCharNumber = incoming - 27; //Get the custom char spot to record to

      currentMode = MODE_RECORD_CUSTOM_CHAR; //modeRecordCustomChar = true; //Change to this special mode
    }
    else if (incoming >> 4 == 1) //This is a scroll/shift command
    {
      /*See page 24/25 of the datasheet: https://www.sparkfun.com/datasheets/LCD/HD44780.pdf
        Bit 3: (S/C) 1 = Display shift, 0 = cursor move
        Bit 2: (R/L) 1 = Shift to right, 0 = shift left
      */

      //Check for display shift or cursor shift
      if (incoming & 1 << 3) //Display shift
      {
        if (incoming & 1 << 2) SerLCD.scrollDisplayRight(); //Go right
        else SerLCD.scrollDisplayLeft(); //Go left
      }
      else //Cursor move
      {
        //Check for right/left cursor move
        if (incoming & 1 << 2) //Right shift
        {
          characterCount++; //Move cursor right
          if (characterCount == settingLCDwidth * settingLCDlines) characterCount = 0; //Wrap condition
        }
        else
        {
          if (characterCount == 0) characterCount = settingLCDwidth * settingLCDlines; //Special edge case
          characterCount--; //Move cursor left
        }
        SerLCD.setCursor(characterCount % settingLCDwidth, characterCount / settingLCDwidth); //Move the cursor
      }
    }
    else if (incoming >> 3 == 1) //This is a cursor or display on/off control command
    {
      /*See page 24 of the datasheet: https://www.sparkfun.com/datasheets/LCD/HD44780.pdf

        Bit 3: Always 1 (1<<3)
        Bit 2: 1 = Display on, 0 = display off
        Bit 1: 1 = Cursor displayed (an underline), 0 = cursor not displayed
        Bit 0: 1 = Blinking box displayed, 0 = blinking box not displayed

        You can combine bits 1 and 2 to turn on the underline and then blink a box. */

      //Check for blinking box cursor on/off
      if (incoming & 1 << 0) SerLCD.blink();
      else SerLCD.noBlink();

      //Check for underline cursor on/off
      if (incoming & 1 << 1) SerLCD.cursor();
      else SerLCD.noCursor();

      //Check for display on/off
      if (incoming & 1 << 2) SerLCD.display();
      else SerLCD.noDisplay();
    }
    else if (incoming >> 4 != 0b00000011) //If not the data length (DL) command then send it to LCD
    {
      //We ignore the command that could set LCD to 8bit mode
      //But otherwise give the user the ability to pass commands directly
      //into the LCD.
      SerLCD.command(incoming);
    }
  }
  else if (currentMode == MODE_RECORD_CUSTOM_CHAR)
  {
    //We get into this mode if the user has sent the correct setting or system command

    customCharData[customCharSpot] = incoming; //Record this byte to the array

    customCharSpot++;
    if (customCharSpot > 7)
    {
      //Once we have 8 bytes, stop listening
      customCharSpot = 0; //Wrap variable at max of 7

      SerLCD.createChar(customCharNumber, customCharData); //Record the array to CGRAM

      //Record this custom char to EEPROM
      for (byte charSpot = 0 ; charSpot < 8 ; charSpot++)
        EEPROM.update(LOCATION_CUSTOM_CHARACTERS + (customCharNumber * 8) + charSpot, customCharData[charSpot]); //addr, val

      //For some reason you need to re-init the LCD after a custom char is created
      SerLCD.begin(settingLCDwidth, settingLCDlines);

      currentMode = MODE_NORMAL; //Exit this mode
    }
  }
  else if (currentMode == MODE_CONTRAST)
  {
    //We get into this mode if the user has sent the ctrl+x (24) command to change contast
    changeContrast(incoming);
    currentMode = MODE_NORMAL; //Exit this mode
  }
  else if (currentMode == MODE_SET_RGB)
  {
    //We get into this mode if the user has sent the + (43) command to set the backlight rgb values
    rgbData[rgbSpot] = incoming; //Record this byte to the array

    rgbSpot++;
    if (rgbSpot > 2)
    {
      //Once we have 3 bytes, stop listening and change the backlight color
      rgbSpot = 0;
      changeBacklightRGB(rgbData[0], rgbData[1], rgbData[2]);
      currentMode = MODE_NORMAL; //Exit this mode
    } //if (rgbSpot > 2)
  } // else if modeSetRGB

}

//Flushes all characters from the frame buffer
void clearFrameBuffer()
{
  //Clear the frame buffer
  characterCount = 0;
  for (byte x = 0 ; x < (settingLCDwidth * settingLCDlines) ; x++)
    currentFrame[x] = ' ';
}

//Display the LCD buffer and return the cursor to where it was before the system message
void displayFrameBuffer(void)
{
  //Return display to previous buffer
  SerLCD.clear();
  SerLCD.setCursor(0, 0);

  for (byte x = 0 ; x < (settingLCDlines * settingLCDwidth) ; x++)
    SerLCD.write(currentFrame[x]);

  //Return the cursor to its original position
  SerLCD.setCursor(characterCount % settingLCDwidth, characterCount / settingLCDwidth);
}

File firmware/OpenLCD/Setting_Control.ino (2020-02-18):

/*
  OpenLCD control for changing settings

  See main file for license and information.
*/

//Toggle the ignore rx setting
void changeIgnore()
{
  settingIgnoreRX = EEPROM.read(LOCATION_IGNORE_RX);

  //Toggle the setting
  if (settingIgnoreRX == true)
    settingIgnoreRX = false;
  else
    settingIgnoreRX = true;

  //Record this new setting
  EEPROM.update(LOCATION_IGNORE_RX, settingIgnoreRX);

  if (settingDisplaySystemMessages == true)
  {
    //Display new settings to the user
    SerLCD.clear();
    SerLCD.setCursor(0, 0);

    SerLCD.print(F("Ignore RX O"));

    if (settingIgnoreRX == false)
      SerLCD.print(F("FF"));
    else
      SerLCD.print(F("N"));

    petSafeDelay(SYSTEM_MESSAGE_DELAY);

    displayFrameBuffer(); //Return the contents of the display
  }
}

//Turn on messages like 'Contrast: 5' when user changes setting
void enableDisplaySystemMessages()
{
  settingDisplaySystemMessages = true;

  //Record this new setting
  EEPROM.update(LOCATION_DISPLAY_SYSTEM_MESSAGES, settingDisplaySystemMessages);

  //Display new setting to the user
  SerLCD.clear();
  SerLCD.setCursor(0, 0);
  SerLCD.print(F("Messages ON"));
  petSafeDelay(SYSTEM_MESSAGE_DELAY);
  displayFrameBuffer(); //Return the contents of the display
}

//Turn off system messsages
void disableDisplaySystemMessages()
{
  settingDisplaySystemMessages = false;

  //Record this new setting
  EEPROM.update(LOCATION_DISPLAY_SYSTEM_MESSAGES, settingDisplaySystemMessages);
}

//Display the current firmware version for a set amount of time
void displayFirmwareVersion()
{
  SerLCD.clear();
  SerLCD.setCursor(0, 0);

  SerLCD.print(F("Firmware v"));
  SerLCD.print(firmwareVersionMajor);
  SerLCD.print(F("."));
  SerLCD.print(firmwareVersionMinor);

  petSafeDelay(SYSTEM_MESSAGE_DELAY);

  displayFrameBuffer(); //Return the contents of the display
}

//Change the digital contrast
//Press a or z to adjust, x to exit
void changeContrast(byte contrast)
{
  EEPROM.update(LOCATION_CONTRAST, contrast); //Store this new contrast

  //Go to this new contrast
  analogWrite(LCD_CONTRAST, contrast);

  if (settingDisplaySystemMessages == true)
  {
    //Display the new contrast
    SerLCD.clear();
    SerLCD.setCursor(0, 0); //First position, 1st row
    SerLCD.print("Contrast Set");
    SerLCD.setCursor(0, 1); //First position, 2nd row
    SerLCD.print(contrast);

    petSafeDelay(SYSTEM_MESSAGE_DELAY);

    displayFrameBuffer(); //Display what was there before
  }
}

//Change the I2C or TWI address
void changeTWIAddress(byte newAddress)
{
  //Record the new address
  EEPROM.update(LOCATION_TWI_ADDRESS, newAddress);

  setupTWI(); //Leverage the regular startup function

  if (settingDisplaySystemMessages == true)
  {
    //Display the new TWI address
    SerLCD.clear();
    SerLCD.setCursor(0, 0); //First position, 1st row

    SerLCD.print("New TWI: 0x");
    SerLCD.print(newAddress, HEX);

    petSafeDelay(SYSTEM_MESSAGE_DELAY);

    displayFrameBuffer(); //Display what was there before
  }
}

//Save the current frame buffer to EEPROM as the splash screen
void changeSplashContent()
{
  //Record the current frame to EEPROM
  for (byte x = 0 ; x < settingLCDlines * settingLCDwidth ; x++)
    EEPROM.update(LOCATION_SPLASH_CONTENT + x, currentFrame[x]);

  if (settingDisplaySystemMessages == true)
  {
    //Display the backlight setting
    SerLCD.clear();
    SerLCD.setCursor(0, 0); //First position, 1st row

    SerLCD.print("Splash Recorded");

    petSafeDelay(SYSTEM_MESSAGE_DELAY);

    displayFrameBuffer(); //Display what was there before
  }
}
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

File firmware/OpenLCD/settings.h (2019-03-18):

//Hardware pin definitions
#define LCD_RS A0
#define LCD_RW A1
#define LCD_EN A2
#define LCD_D4 A3
#define LCD_D5 2
#define LCD_D6 7
#define LCD_D7 4
#define BL_RW 5 //PWM
#define BL_G  6 //PWM
#define BL_B  3 //Not PWM so we use SoftPWM
#define SIZE_JUMPER 8
#define LCD_CONTRAST 9 //PWM

#define SPI_CS 10 //As a slave device CS pin must always be 10
#define SPI_MOSI 11
#define SPI_MISO 12
#define SPI_SCK 13

//Define the different baud rate levels
#define BAUD_1200	0
#define BAUD_2400	1
#define BAUD_4800	2
#define BAUD_9600	3
#define BAUD_14400	4
#define BAUD_19200	5
#define BAUD_38400	6
#define BAUD_57600	7
#define BAUD_115200	8
#define BAUD_230400	9
#define BAUD_460800	10
#define BAUD_921600	11
#define BAUD_1000000	12

const byte DEFAULT_TWI_ADDRESS = 0x72; //0x71 for Serial7Segment. 0x72 for SerLCD.
const byte DEFAULT_BAUD = BAUD_9600;  //9600 for 8MHz, 2x speed
const byte DEFAULT_RED = 255;
const byte DEFAULT_GREEN = 255;
const byte DEFAULT_BLUE = 255;
const byte DEFAULT_LINES = 2;
const byte DEFAULT_WIDTH = 16;
const byte DEFAULT_SPLASH = true; //Default on
const byte DEFAULT_CONTRAST_LCD = 5;
const byte DEFAULT_DISPLAY_SYSTEM_MESSAGES = true; //Enable messages

//Internal EEPROM locations for the user settings
#define LOCATION_BAUD 0
#define LOCATION_TWI 1
#define LOCATION_SPLASH_ONOFF 2
#define LOCATION_LINES 3
#define LOCATION_WIDTH 4
#define LOCATION_RED_BRIGHTNESS 5
#define LOCATION_GREEN_BRIGHTNESS 6
#define LOCATION_BLUE_BRIGHTNESS 7
#define LOCATION_IGNORE_RX 8
#define LOCATION_TWI_ADDRESS 9
#define LOCATION_CONTRAST 10 //8 bit
#define LOCATION_DISPLAY_SYSTEM_MESSAGES 11 //8 bit
#define LOCATION_SPLASH_CONTENT 20 //This is 4*20 or 80 bytes wide
#define LOCATION_CUSTOM_CHARACTERS 100 //This is 8*8 or 64 bytes wide

//Define the various commands
#define SPECIAL_COMMAND 254 //0xFE: The command to do special HD77480 commands
#define SPECIAL_SETTING '|' //124, 0x7C, the pipe character: The command to do special settings: baud, lines, width, backlight, splash, etc

#define SPECIAL_RED_MIN 128 //Command minimum for red/white backlight brightness
#define SPECIAL_GREEN_MIN (SPECIAL_RED_MIN+30) //Command for green backlight brightness
#define SPECIAL_BLUE_MIN (SPECIAL_GREEN_MIN+30) //Command for blue backlight brightness

//Used for the different color backlights
#define RED    0
#define BLUE   1
#define GREEN  2

const byte BUFFER_SIZE = 128; //Number of characters we can hold in the incoming buffer
const byte DISPLAY_BUFFER_SIZE = 4*20; //4x20 the max number of characters we will display at one time

#define SYSTEM_MESSAGE_DELAY 500 //Amount of time (ms) we spend displaying splash and system messages

//Global setting variables
byte settingLCDwidth;
byte settingLCDlines;
bool settingSplashEnable;
byte settingUARTSpeed;
bool settingIgnoreRX;
bool settingDisplaySystemMessages; //User can turn on/off the messages that are displayed when setting (like contrast) is changed

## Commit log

2015-02-17 Initial commit.
    Files are in an unknown state. Just getting everything moved over to new
    repo.
    [OpenLCD.brd, OpenLCD.sch]
2015-03-11 Board layout complete
    [OpenLCD.brd, OpenLCD.sch]
2015-03-12 Adding jumpers for size and voltage.
    [OpenLCD.brd, OpenLCD.sch]
2015-03-18 Standard I2C interface. I2C pull ups. VCC on FTDI connector.
    Added silk to both sides. Moved contrast pin to PWM pin and direct
    connect.
    [OpenLCD.brd, OpenLCD.sch]
2015-03-18 Final touchup before QC review.
    [OpenLCD.brd, OpenLCD.sch]
2015-03-24 Resolved issue 1
    [OpenLCD.brd, OpenLCD.sch]
2015-03-25 Correcting silk
    [OpenLCD.brd, OpenLCD.sch]
2015-03-25 Updated SFE logos and flames
    To avoid extremely long CAM jobs in eagle 7.2
    [OpenLCD.brd, OpenLCD.sch]
2015-06-16 Adding Arduino examples. Renaming main firmware.
    [OpenLCD.brd, OpenLCD.sch]
2015-11-02 Add back contrast trimpot. Add Bypass jumper.
    Software contrast control is unreliable on too many types of LCDs.
    Returned to a trimpot. Added a bypass jumper to allow for LCDs with
    larger backlight requirements.
    [OpenLCD.brd, OpenLCD.sch]
2015-11-03 Adding custom character support
    Doesn't work yet but getting it figured out.
    [OpenLCD.brd]
2015-11-03 Connected blue backlight control pin to PWM on ATmega
    [OpenLCD.brd, OpenLCD.sch]
2015-11-04 Added MCP4725 for contrast control. Changed to 10uF tantulum.
    We're going to try using the internal band gap reference for temp
    control and modify the contrast based on that temp. We'll see if it
    works...
    [OpenLCD.brd, OpenLCD.sch]
2015-11-09 Fixes for issue #4.
    [OpenLCD.brd, OpenLCD.sch]
2015-11-09 Getting closer to supporting custom characters
    Works but need to record custom chars to EEPROM and load them upon power
    up.
2015-11-11 Adding EEPROM support for custom chars. Fixing trace/space issue #4.
    [OpenLCD.brd]
2017-02-21 Changes the pins to work with v2 protos. Added custom char support.
    [OpenLCD-Dimension For Spec.brd, OpenLCD-Dimension For Spec.sch, OpenLCD.sch]
2018-07-26 Re-organized and renamed all example codes
    Pre-fixed all example sketches with "Example1_..." and so on.
    Split out communication style into sub-directories - Serial, I2C, SPI, Advanced
    [Example10_Serial_SoftwareReset.ino, Example1_I2C_Basic.ino, Example1_SPI_Basic.ino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]
2018-07-30 SPI example - corrected csPin, and slowed down for consistency
    Comment says D10 for cdPin, so just adjusted to match.
    At clock divide 64, it was missing a few characters here and there. It's still not perfect, but at least it's only hiccuping once in a while at clock div 128.
    [Example1_SPI_Basic.ino]
2018-08-02 exported firmware HEX FILE from arduino
    Handy to have this in the repo, in case you want to upload over ISP, and for the link on the product page.
2018-08-02 Nothing to see here
    clearing out some stuff from product development and various design phases
    [OpenLCD-Dimension For Spec.brd, OpenLCD-Dimension For Spec.sch, OpenLCD.brd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]
2018-08-21 Add files via upload
    Fixed a bug (Fence Post error) in the Display Customer character command that allowed the user to request a ninth character when only 8 are allowed. The upper limit in the if statement was off by one. The allowable range should be 35 to 42, inclusive, not 35 to 43.
    [OpenLCD.ino]
2018-08-24 Add logic to print pipe if second control chracter is read
    This allows the user to print a pipe control character to the display by escaping the control character as a double pipe
2018-08-28 Fix size of array and add demo of new command
    [OpenLCD.ino]
2018-08-28 Fix comment and add missing debug statements to demo code
    [OpenLCD.ino]
2018-08-28 Changing I2C backlight example to show new method. Removing dead/old advanced sketches. Updating cheatsheet in examples.
2018-09-15 Change order in which version is printed
2018-09-16 Fixed 'display firmware' command. It was overlapping on custom chars.
    [OpenLCD.ino, System_Functions.ino]
2019-01-30 Updated all references of EEPROM.write to EEPROM.update
    Patch to reduce unnecessary EEPROM writes by using .update() method, which compares the current value. The comparatively small cost of the read should be more than made up for by the reduction in writes for most operations. Also since there is currently no way to read the settings back, it reduces writes where firmware needs to set the OpenLCD to a default state every reset.
    [OpenLCD.ino, Setting_Control.ino, System_Functions.ino]
2019-01-31 Add whitespace to header comments to get linker to work
    Without these extra spaces the sketch fails to compile because the pre-processor doesn't correctly create the prototypes of functions in the tabs.
    [OpenLCD.ino]
2019-02-12 Created combined hex of current firmware
    for production programming
2019-03-17 Fix bug which disables emergency reset by default
    Initialize settingIgnoreRX to false.
    In emergency reset, use default value for contrast instead of literal, and set brightnesses to defaults.
    [System_Functions.ino]
2019-03-17 Fix backward logic displaying settingIgnoreRX
    [Setting_Control.ino]
2019-03-19 enable true off for blue LED
    SoftPWM has a true off (0 is really off), but not a true on (255 is not 100% duty cycle), so invert the logic to be able to fully turn off the blue LED.
    [Setting_Control.ino, System_Functions.ino]

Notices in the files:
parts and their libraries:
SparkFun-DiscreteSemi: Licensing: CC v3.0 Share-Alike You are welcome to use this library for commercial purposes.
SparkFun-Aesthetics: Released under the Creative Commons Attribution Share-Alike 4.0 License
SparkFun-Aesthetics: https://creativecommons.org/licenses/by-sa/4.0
